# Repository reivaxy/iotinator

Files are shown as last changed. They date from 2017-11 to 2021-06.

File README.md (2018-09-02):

# iotinator

## The DIY multipurpose home iot solution.

### Some use cases

You come home, use your phone to browse to http://my.iotinator.com and turn on the light of the living room and adjust its brighness.

You are about to come home, use your phone to remotely turn the heater on so that the appartment is comfy when you get there.

You are on vacation, receive alerts if your aquarium temperature drops abnormally.

... etc, etc.

### Project description

TL;DR: This is not just a framework or a library, it's an iot application you can already use. Please check the Wiki for a detailed walk-through introduction and many pictures: https://github.com/reivaxy/iotinator/wiki

Here is the master module with a prototype switch module

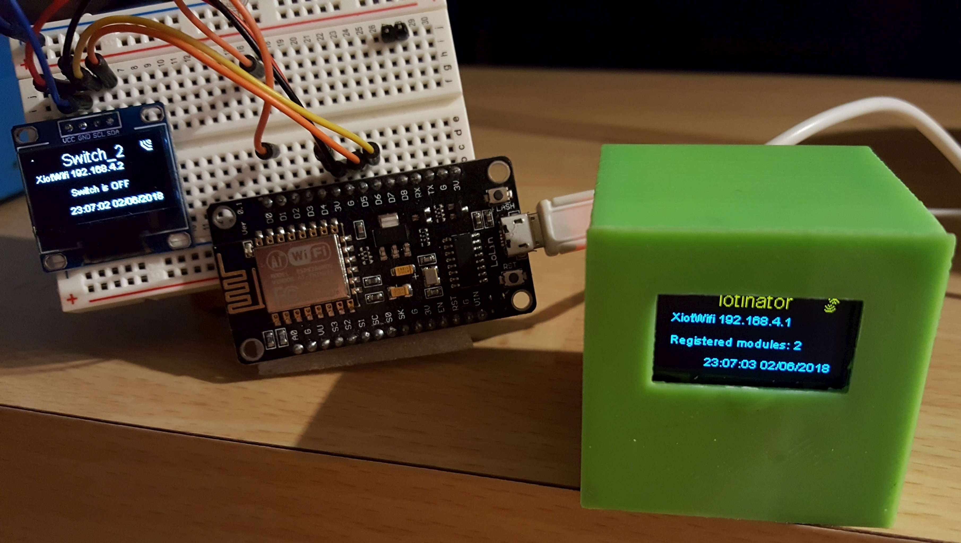
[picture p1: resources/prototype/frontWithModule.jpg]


And here is the switch module encased and functional:

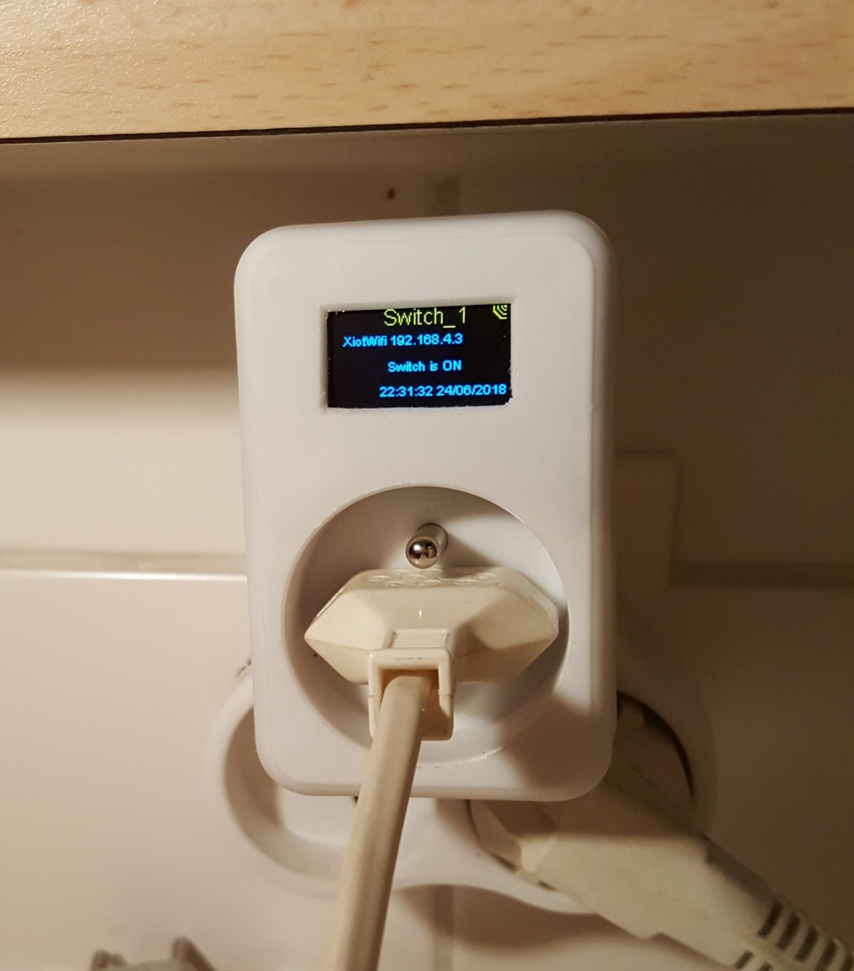
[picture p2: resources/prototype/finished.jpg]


You can easily build already available modules, which are usually just a few dollars of very easy to find hardware.

But you can easily design your own modules to fit your needs: in just a few lines of code, you can design a module able to connect to a wifi network, and equipped with a tiny Oled screen, to monitor something or control it, and make its collected data and actions available through a webApp showing all connected modules, but also through sending and receiving GSM text messages (not yet ready).

You can also update your modules wirelessly once in place, to keep improving them.

Some can operate using a small battery, others will need a power adapter, others can run directly on your main power source, or on a solar source.

Examples of modules are:
- Turning on/off a lamp, a heater, an air conditionner (Existing https://github.com/reivaxy/iotSwitch module)
 
 Here is a picture of this module's Oled display (Don't be fooled by its blurry aspect, the screen is actually sharp and good looking)
 
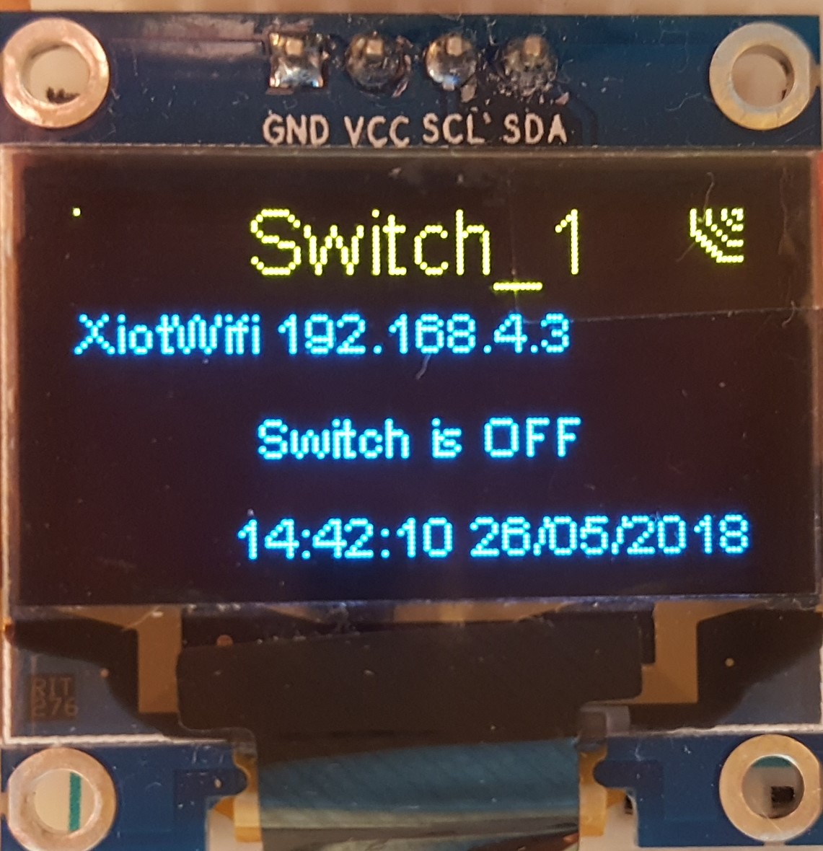
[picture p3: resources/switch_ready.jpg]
  
  
- A programmable scheduler to turn on/off random devices. Derived from the iotSwitch module by just adding some scheduling feaures.
- Monitoring for water leaks to send alerts (push, sms, ...)
- Monitoring for fire/fumes to send alerts
- Monitoring an aquarium parameters to alert when something's off (the very source of this project idea, which I had while working on https://github.com/reivaxy/aquaMonitor)
- Controlling various devices through their IR remote control port, replacing many remote controls with the advantage of working according to a programmed schedule, or remotely from home, which can be nice to set the heater or A/C on a little before coming home.
- You name it !

### And if you want to know more...

Let's dive deeper:

Xiot is a framework consisting of set of classes available as libraries, that make easy Wifi connection, Oled screen display, information exchange, web app interface.

An Xiot swarm is composed of a iotinator "master" module, and a bunch of agent modules (bunch start at one...).

Iotinator is the master module of the Xiot framework.

Its goal is to control many different devices by SMS or through a webApp (or mobile app), it's the common entry (and exit) point of communication. Once the master module is configured, adding a module is zero configuration: power the module up, reset the master, the new module will connect, and they'll negociate what happens next, which is use a private wifi network. Pre existing and connected modules will be disconnected for 30 seconds and automatically reconnect.

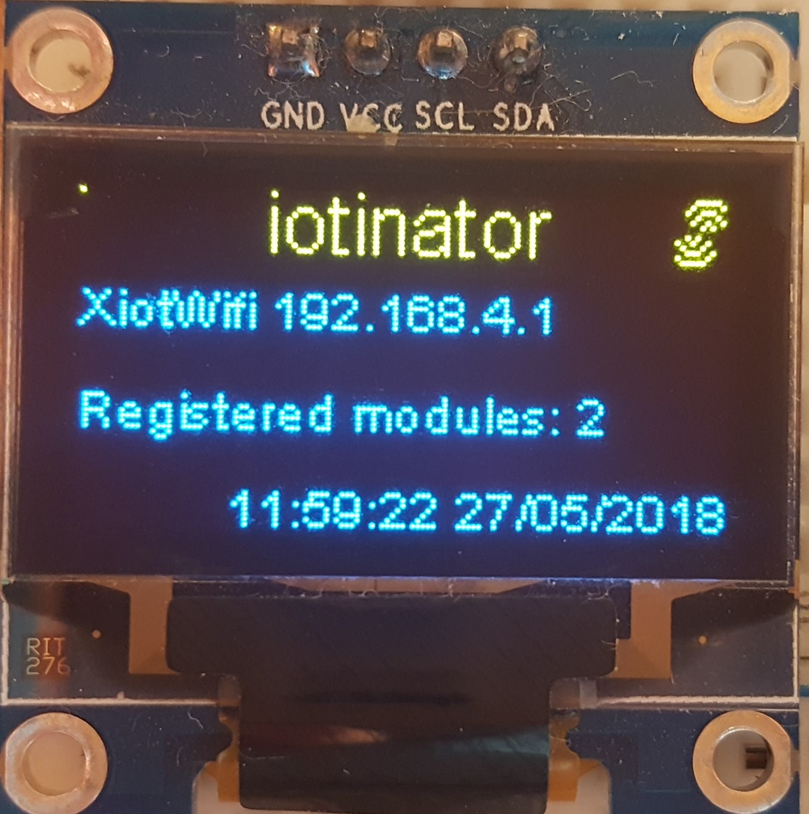
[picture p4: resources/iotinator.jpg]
  

Designing a new module can be just a few lines of code, depending on its complexity, of course.

The master and the modules run on esp8266 hardware (will investigate esp32 hardware too, one board having an Oled screen already integrated), connected to a SIM900 chip and an Oled screen, and offers an interface to agent modules in order to monitor them through SMS and webApps.

The Iotinator master module exposes APIs to communicate with the modules, and dispatches and forwards messages received by SMS or from the web app to them, and sends their responses back.

These API also allow modules to record logs, stats, etc on a website, and expose a web UI for module configuration and status diplay.

It connects to a domestic Wifi network to get time through NTP servers (but it can also get time from GSM network), and record logs and stats on a web server, much like http://reeftankalert.com/chart.php) and exposes a "private" Wifi network to communicate with agent modules.

Configuration is persisted in EEPROM, it uses network autodiscovery, (re)connection management is automatic.

# Current Status:

Waiting to solve stability issues with cheap GSM boards, gsm handling has been disabled.

GSM will be an option, the framework being able to work just using internet.

But GSM is nice in case of power outage (modules can have batteries, but my adsl box doesn't), and also to handle security
(sending codes to validate authentication for instance)

Current time is fetched from NTP servers once Home Wifi is configured and connected. The master module registers to the parameterized website (default is http://www.iotinator.com, whose files are in the webSite directory), so that if your phone is connected to the same network, typing http://my.iotinator.com will redirect you to the webApp.

The framework currently allows to create a new module in :
* a few lines of CPP in which you implement your custom eeprom persisted settings and behaviors, including displaying custom info on the Oled screen.
* a few lines of JS and CSS in which you implement the custom UI elements exposed on the webApp

The framework takes care of wifi connection to the iotinator master, registration, data exchange, polling, time and display management.

To create a new module, just get the iotSwitch repo, rename it, and the files within, and the classes they contain, and the code is totally self explanatory (No, just kidding).

For now the UI files (js, css) of each module are in the iotinator repository, which is not awesome...

The UI framework is taking care of displaying one block for each module connected with their connection information and providing the module's generic and custom data, and each module needs to provide the UI elements to display/handle its custom data within these blocks, and send actions to the REST api.

The UI part is not offering enough in terms of framework, and may change drastically. I'd like to investigate a vueJs or mobxJs version. Several UIs could easily be made available at the same time anyway.

Most UI files (all but one) need to be hosted on a public web server, because of low capacity on ESP8266 both in terms of storage and performances. I don't want to bloat it with an SD card, it has better things to do.

The js and css files are loaded from the minimalist loader page served by the module to build the webApp, which allows to modify the webApp without the need for flashing the ESP8266 to improve it, or translate messages. This also makes using images really easier, and contributes to faster page loading, since the wifi module does not have a great bandwidth (and does not process multiple requests simultaneously).

Of course you'll need to add the .htaccess directive:

Header set Access-Control-Allow-Origin "*"

In the wiki, you'll find all the information to setup your development environment, the libraries to install, and the necessary hardware.

https://github.com/reivaxy/iotinator/wiki

Picture of the early prototype with its SIM800 board:

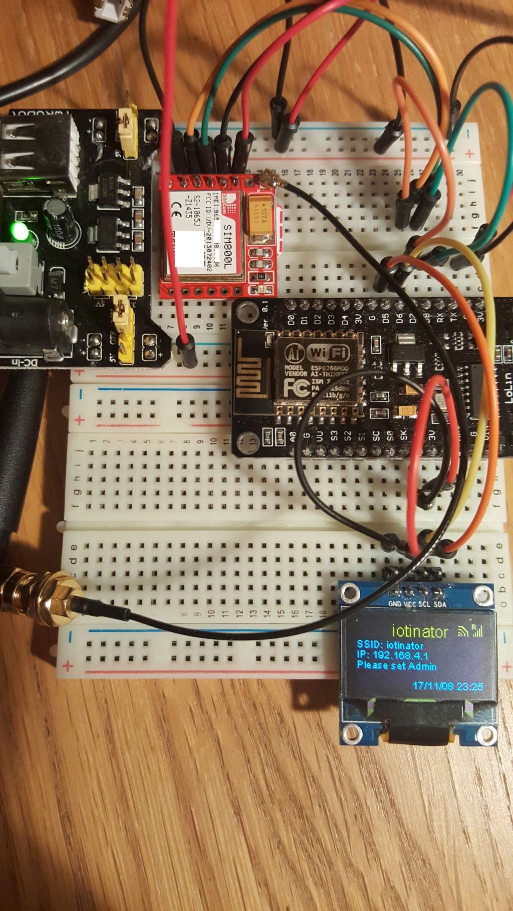
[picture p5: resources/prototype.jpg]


Screen shot of the POC of the webApp, showing 3 connected modules.

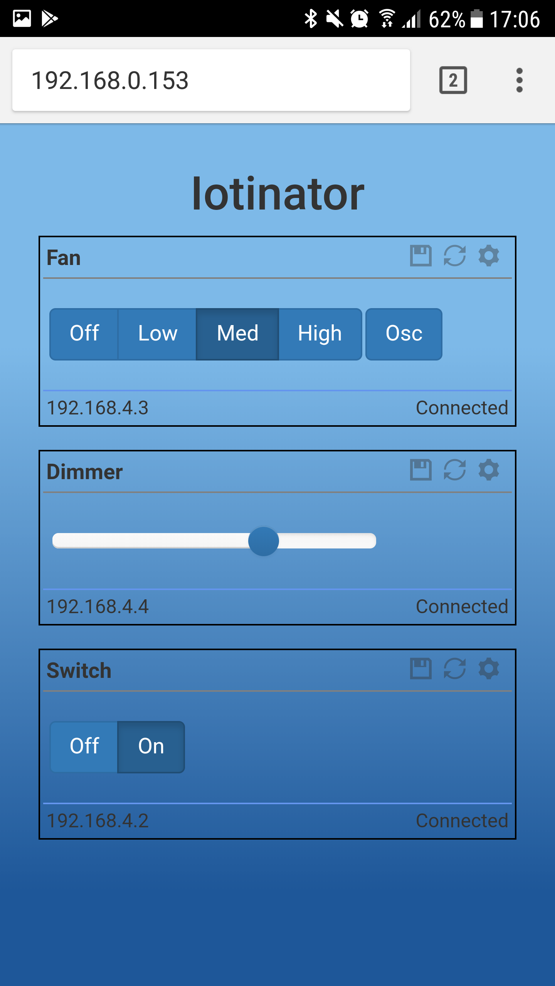
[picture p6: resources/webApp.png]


The data is refreshed every 10 seconds and reflects the status of the modules. A click on the button allows to control the Switch.

The UI is using Backbone and Bootstrap. A less than 1K page is served by the master ESP8266, and the rest of the API (libs, css, js) are hosted on a regular public server.

It's fast and light !

The iotSwitch module (https://github.com/reivaxy/iotSwitch) is basic but some will be more complex soon (Most of it coming from my previous project https://github.com/reivaxy/aquaMonitor/blob/master/res/webApp.png)

The iotFan (https://github.com/reivaxy/iotFan) module is merely a module that can control 4 switches, I used it in an old fan to remotely select its rotation speed.

The iotDimmer (https://github.com/reivaxy/iotDimmer) module is a dimmer I use to control the light level in my living room. It can also be used to control the speed of a fan (will depend on the motor technology, though).

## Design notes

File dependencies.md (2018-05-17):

https://github.com/esp8266/Arduino/tree/master/libraries/ESP8266WebServer

ESP8266WiFi

git@github.com:ThingPulse/esp8266-oled-ssd1306.git 

http://www.arduino.cc/en/Reference/Ethernet

NtpClientLib by German Martin 2.5.0
Time by Michael Margoli1.5.0

- https://github.com/reivaxy/XOLEDDisplay.git 
- https://github.com/reivaxy/XIOTDisplay.git
- https://github.com/reivaxy/XEEPROMConfig.git
- https://github.com/reivaxy/XUtils.git
- https://github.com/reivaxy/XIOTModule.git

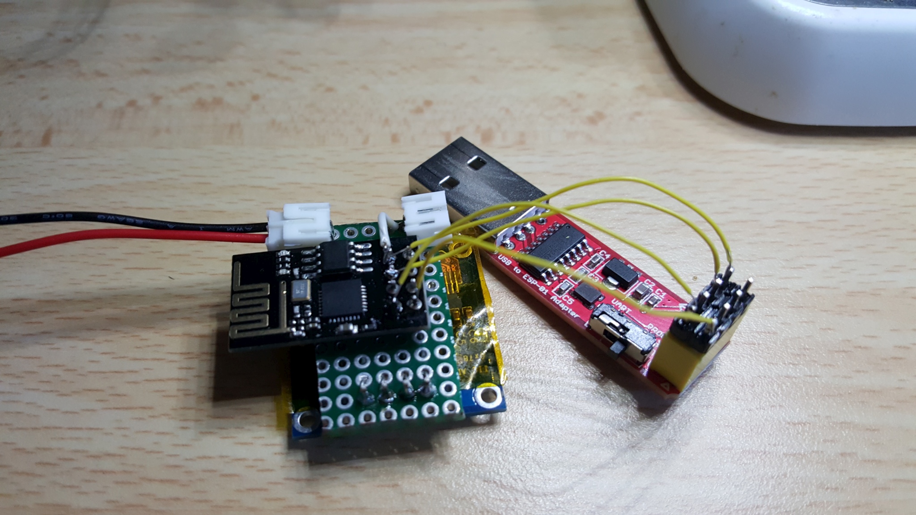
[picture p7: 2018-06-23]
resources/prototype/reFlash.jpg

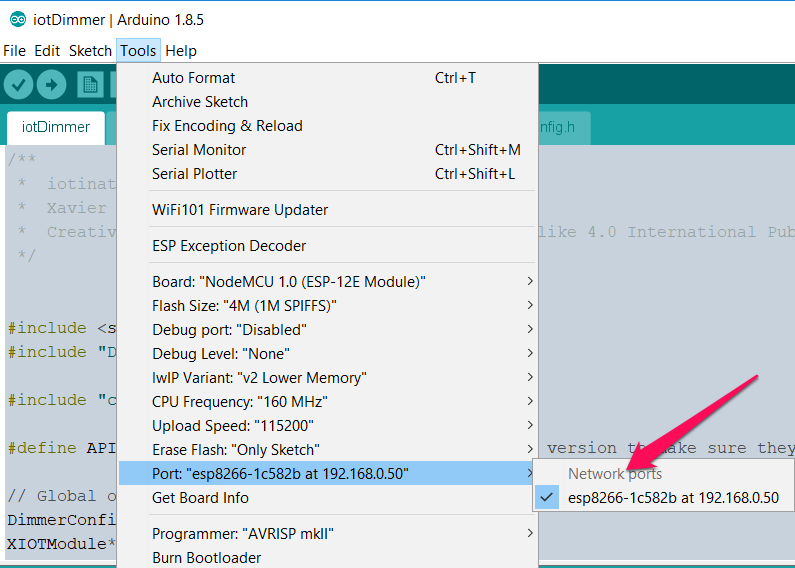
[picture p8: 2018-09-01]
resources/OTA/wifiPort.png

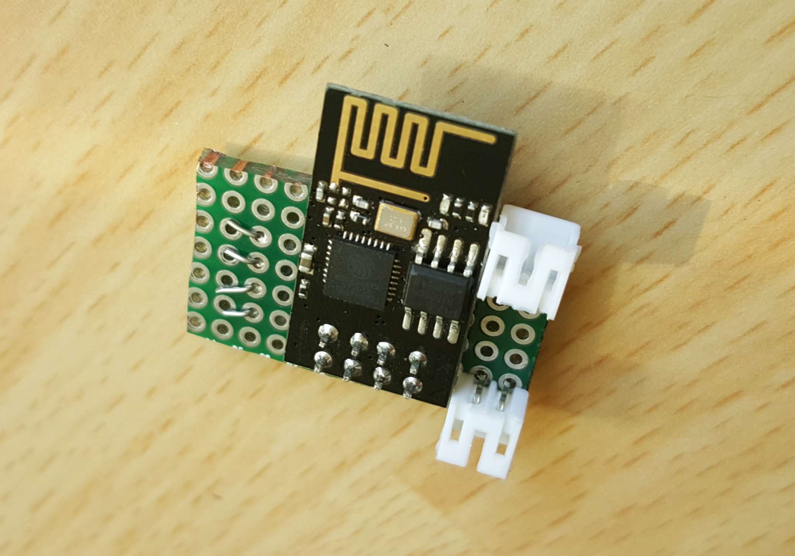
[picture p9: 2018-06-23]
resources/prototype/esp01.jpg

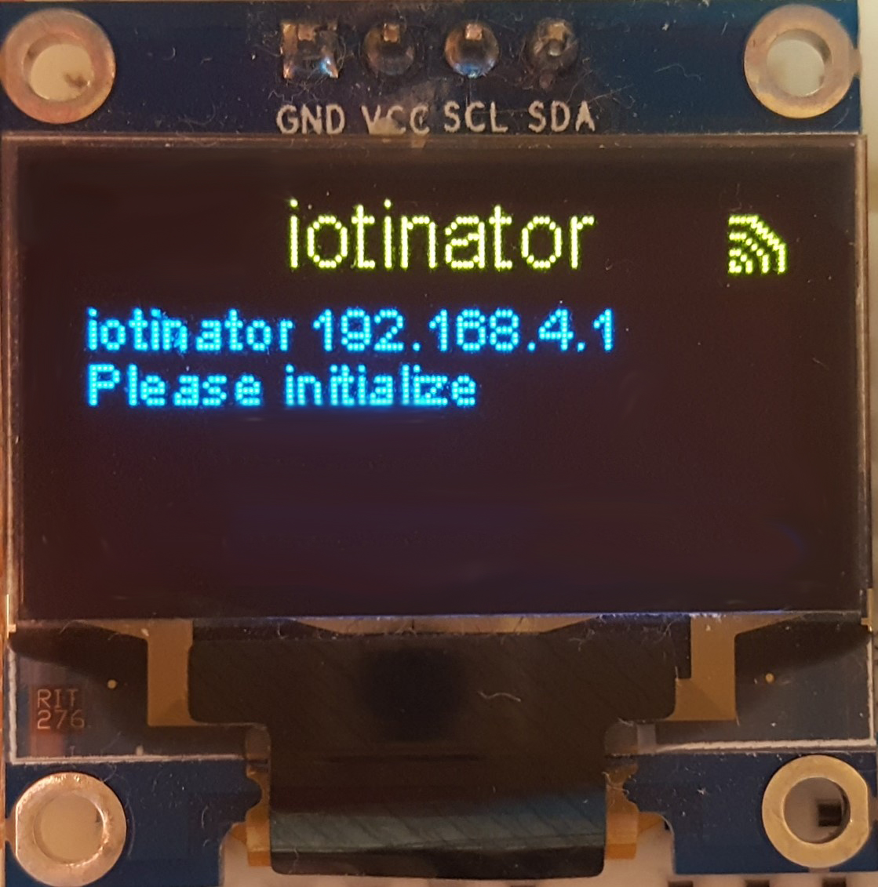
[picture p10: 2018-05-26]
resources/iotinator_init.jpg

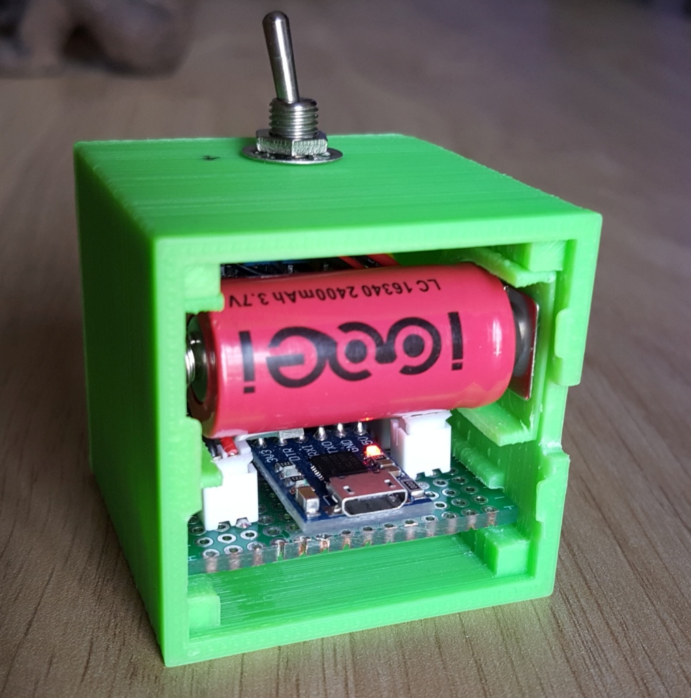
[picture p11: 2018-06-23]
resources/prototype/withBattery.jpg

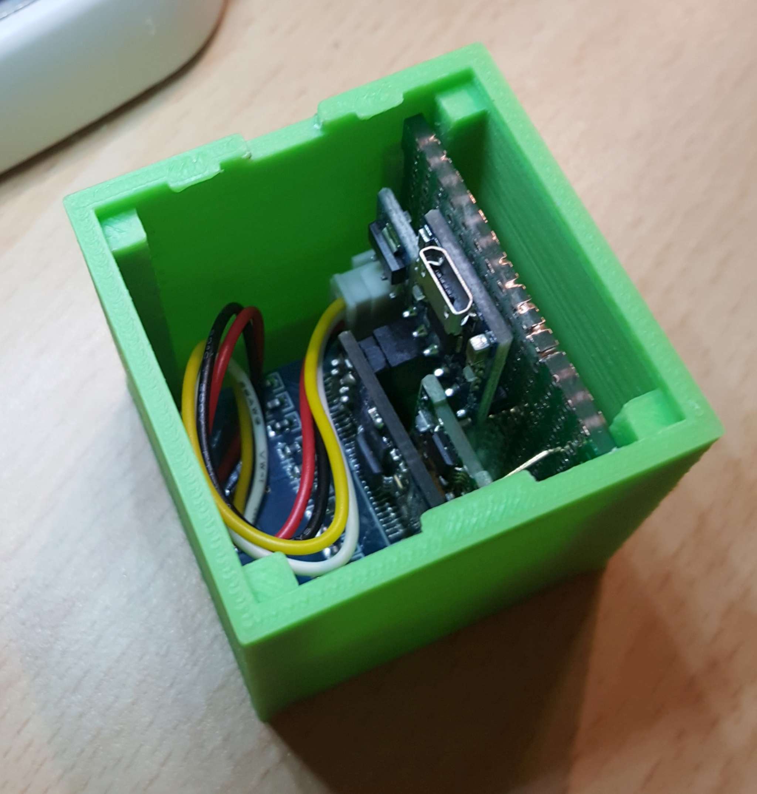
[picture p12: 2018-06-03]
resources/prototype/inside.jpg

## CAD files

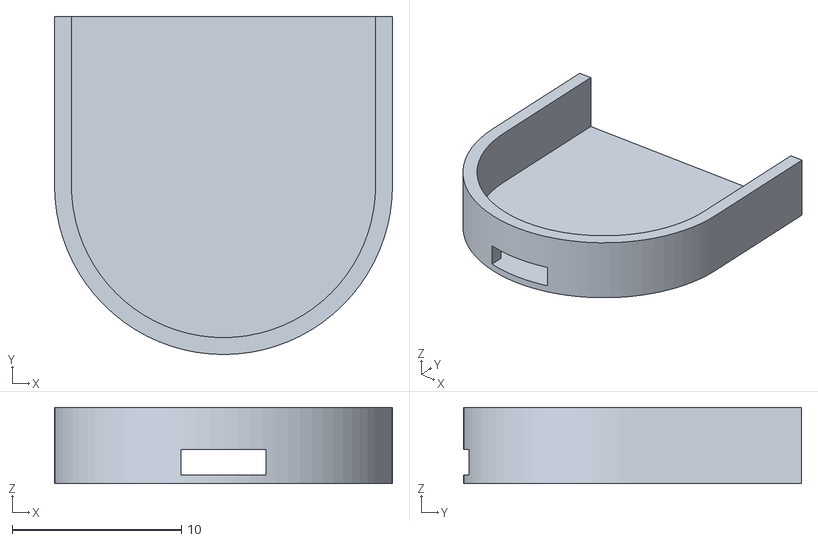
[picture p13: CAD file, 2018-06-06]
hardware/prototype/battery.stl
20.0 x 20.0 x 4.50

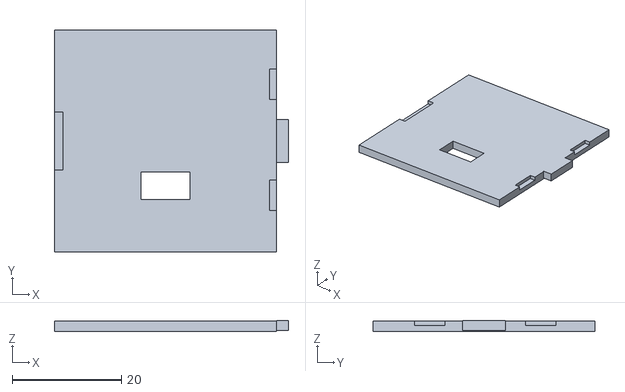
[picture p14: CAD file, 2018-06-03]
hardware/prototype/cover.stl
42.8 x 40.6 x 2.00

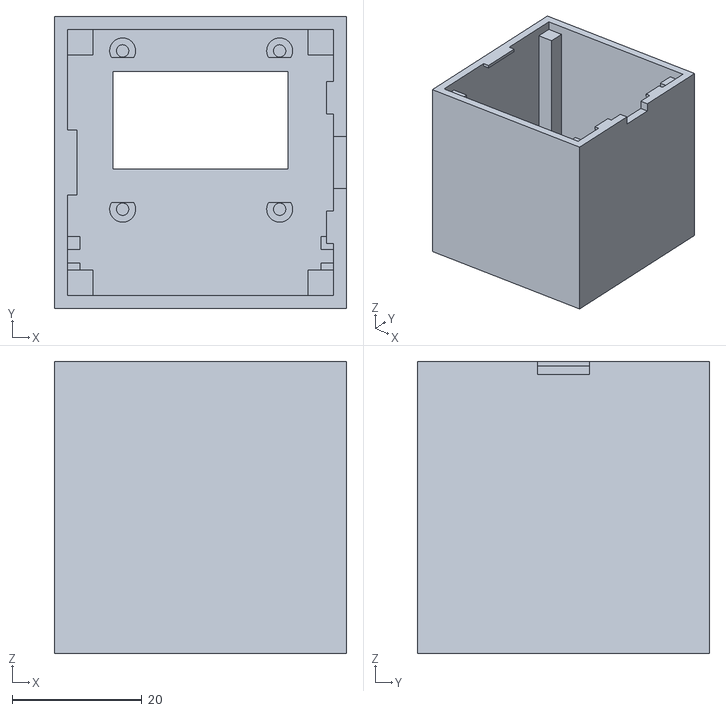
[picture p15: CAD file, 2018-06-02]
hardware/prototype/prototype.stl
45.0 x 45.0 x 45.0

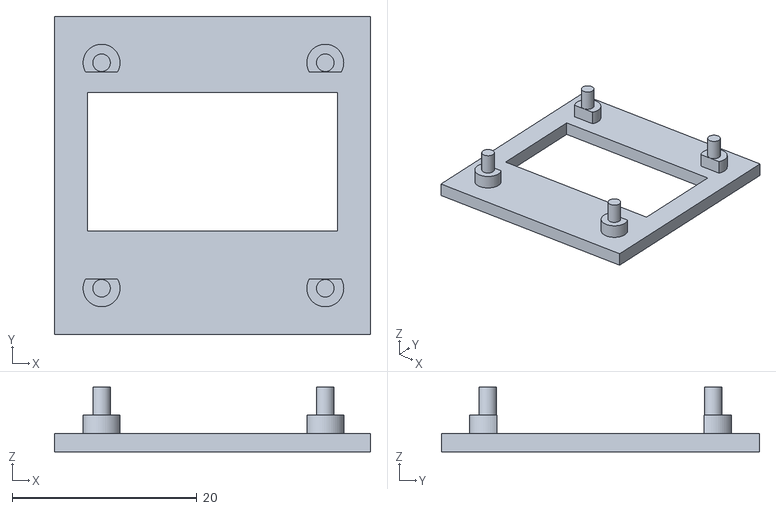
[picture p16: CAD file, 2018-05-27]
hardware/prototype/oledPanel.stl
34.2 x 34.4 x 7.00

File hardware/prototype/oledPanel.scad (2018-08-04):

// Oled screen panel

// Screen dimensions (may vary a little)
screenX = 28.5;
screenY = 27.5;

// Dimensions between holes axis
xInterHole = 23.7;
yInterHole = 24.4;

// Dimensions of the window in the panel
xWindow = 27;
yWindow = 15;
yWindowoffset = 1.5;

// Some offset
xHoleCenter = 0.1;
yHoleCenter = 0;

//rWindowPanel(45, 45, 2, 6);
//windowPanel(45, 45, 2, 6);

module rWindowPanel(x, y, z, yOffset) {
  translate([y/2, x/2, 0])
    rotate(90, [0, 0, 1])
      translate([-x/2, -y/2, 0])
        windowPanel(x, y, z, yOffset);
}

module windowPanel(x, y, z, yOffset) {
  xPanel = x;
  yPanel = y;
  zPanel = z;
  
  difference() {
    oledPanel(xPanel, yPanel, zPanel, yOffset);
    translate([(xPanel - xWindow)/2, (yPanel - yWindow)/2 + yWindowoffset + yOffset, -zPanel/2]) {
      // opening
      cube([xWindow, yWindow, 2 * zPanel]);  
    }
  }
}


module oledPanel(xPanel, yPanel, zPanel, yOffset) {   
  xMargin = xPanel - xInterHole;
  yMargin = yPanel - yInterHole;
  difference() {
    union() {
      cube([xPanel, yPanel, zPanel]);  
      pillar(xHoleCenter, yHoleCenter + yOffset, xMargin, yMargin, zPanel);
      pillar(xHoleCenter + xInterHole, yHoleCenter + yOffset, xMargin, yMargin, zPanel);
      pillar(xHoleCenter, yHoleCenter + yInterHole + yOffset, xMargin, yMargin, zPanel);
      pillar(xHoleCenter + xInterHole, yHoleCenter + yInterHole + yOffset, xMargin, yMargin, zPanel);
    }
    // cut the base of pillars
    translate([(xMargin - yInterHole)/2,  yMargin/2+1 + yOffset, zPanel]) {
      cube([xInterHole *2, yInterHole - 2, 3]);
    }
  }
}

// To hold the Oled screen
module pillar(x, y, xMargin, yMargin, zPanel) {
  echo (x, y, xMargin, yMargin, zPanel);
  translate([x + xMargin/2, y + yMargin/2, zPanel]) {
    cylinder(d=1.6, h=5, $fn=50);
    cylinder(d=4, h=1.5, $fn=50);
  }
    
}

// Screen model to make simulations
module screen() {
  screenY2 = 19;
  z1 = 1.2;
  z2 = 1.5;
  sBottomOffset = 3.7;

  xMargin = screenX - xInterHole;
  yMargin = screenY - yInterHole;
  
  translate([0, sBottomOffset, 0]) {
    cube([screenX, screenY2, z2]);
  }
  translate([0, 0, z2]) {
    difference() {
      cube([screenX, screenY, z1]);
      hole(xHoleCenter, yHoleCenter, xMargin, yMargin, z1);
      hole(xHoleCenter + xInterHole, yHoleCenter, xMargin, yMargin, z1);
      hole(xHoleCenter, yHoleCenter + yInterHole, xMargin, yMargin, z1);
      hole(xHoleCenter + xInterHole, yHoleCenter + yInterHole, xMargin, yMargin, z1);
      // pin placeholders
      translate([(screenX - 11)/2, screenY-3, z1 - 0.1]) {
        cube([11, 2.6, 1]);
      }
    }
  }
}

module hole(x, y, xMargin, yMargin, z) {
  translate([x + xMargin/2, y + yMargin/2, -0.1]) {
    cylinder(d=1.9, h = z+0.2, $fn=20);
  }
  
}

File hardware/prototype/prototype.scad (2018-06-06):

include <oledPanel.scad>;


innerX = 41;
innerY = 41;
innerZ = 41;
wall = 2;

outerX = innerX + 2 * wall;
outerY = innerY + 2 * wall;
outerZ = innerZ + 2 * wall;

boardZ = 2.25;

leftHookY = 10;
leftHookZ = 0.7;
leftHookX = 1.5;

rightHookY = 5;
rightHookZ = 0.7;
rightHookX = 1.1;

indentX = wall;
indentY = 8;
indentZ = wall;

rail = 2;
corner = 4;

batteryBracket();

//cover();
// iotinator();
//closed();

module closed() {
  iotinator();
  translate([wall + coverTolerance/2, wall + coverTolerance/2, outerZ - wall]) {
    cover();
  }
}


module batteryBracket() {
  x = 20;
  x2 = 18;
  z = 4.5;
  difference() {
    union() {
      cube([x, x/2, z]);
      translate([x/2, 0, 0]) {
        cylinder(d=x, h=z, $fn=80);
      }
    }
    union() {
      translate([x/2, 0, 0.5]) {
        cylinder(d = x2, h = z, $fn = 80);
      }
      translate([(x - x2)/2, 0, 0.5]) {
        cube([x2, x2, z]);
      }
    }
    translate([(x - 5)/2, -x/2, 0.5]) {
      cube([5, 1.5, 1.5]);
    }
  }
}


module iotinator() {
  windowPanel(outerX, outerY,  wall, 4);  
  difference() {
    // outer cube
    cube([outerX, outerY, outerZ]);
    translate([wall, wall, -wall]) {
      // inner cube
      cube([innerX, innerY, innerZ + 4 * wall]);
    }
    
    // Small opening for the cover
    translate([innerX + wall -1 , (outerY - indentY)/2, outerZ-indentZ]) {
      cube([indentX + 2, indentY, indentZ+1]);
    }      
  }
  
  // bottom left rail
  translate([wall, wall + corner, 0])
    cube([rail, rail, innerZ-5]);
  // top left rail
  translate([wall, wall + corner + rail + boardZ, 0])
    cube([rail, rail, innerZ-5]);
  // bottom right rail
  translate([innerX + wall - rail , wall + corner, 0])
    cube([rail, rail, innerZ-5]);
  // top right rail
  translate([innerX + wall - rail , wall + corner + rail + boardZ, 0])
    cube([rail, rail, innerZ-5]);
  
  // bottom left corner
  translate([wall, wall, wall])
    cube([corner, corner, innerZ]);
  // top left corner
  translate([wall , innerY + wall - corner , wall])
    cube([corner, corner, innerZ]);
    
  // bottom right corner
  
  translate([innerX + wall - corner, wall, wall])
    cube([corner, corner, innerZ]);
  // top right corner
  translate([innerX + wall - corner, innerY + wall - corner, wall])
    cube([corner, corner, innerZ]);
  
  // left cover Hook
  translate([wall, (outerY - leftHookY)/2, outerZ-leftHookZ]) {
    cube([leftHookX, leftHookY, leftHookZ]);
  }
  
  color("red") {
    // bottom right cover Hook
    translate([outerX - rightHookX - wall, (outerY - rightHookY)/4, outerZ-rightHookZ ]) {
      cube([rightHookX, rightHookY, rightHookZ]);
    }
    // top right cover Hook
    translate([outerX - rightHookX - wall, (outerY - rightHookY) - (outerY - rightHookY)/4, outerZ-rightHookZ ]) {
      cube([rightHookX, rightHookY, rightHookZ]);
    }   
  }
}

coverTolerance = 0.4;
coverX = innerX - coverTolerance;
coverY = innerY - coverTolerance;
usbSocketX = 9;
usbSocketY = 5;
usbSocketYOffset = 9.6;

module cover() {
    union() {
      difference() {
        cube([coverX, coverY, wall - 0.1]);
        
        translate([0, (coverY - leftHookY - 0.6)/2, wall - leftHookZ - 0.2])
          cube([leftHookX +0.1, leftHookY + 0.6, rightHookZ + 2 ]);
        
        // bottom right cover Hook
        translate([coverX - rightHookX -0.2, (coverY - rightHookY - 0.6)/4 - (wall + coverTolerance)/2,  wall - rightHookZ - 0.2]) {
          cube([rightHookX+0.2, rightHookY+0.6, rightHookZ + 2]);
        }
        // top right cover Hook
        translate([coverX - rightHookX -0.2,  
                   (coverY - rightHookY -0.2) - (coverY - rightHookY - 0.6)/4  + (wall + coverTolerance)/2,
                    wall - rightHookZ - 0.2 ]) {
          cube([rightHookX+0.2, rightHookY+0.6, rightHookZ + 2]);
        }
        // usb socket
        translate([(coverX - usbSocketX)/2, usbSocketYOffset, -0.5]) {
          cube([usbSocketX, usbSocketY, wall + 1]);  
        }

      }
      translate([coverX , (coverY - indentY + 0.2)/2, 0.2]) {
        cube([indentX + 0.2, indentY - 0.2, wall - 0.2]);
      }
    }
  
  
}

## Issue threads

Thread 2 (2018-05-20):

Name suffixed with "_1" upon registration

reivaxy, 2018-05-20:
even when no collision

reivaxy, 2023-10-25:
This is a test
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

reivaxy, 2023-10-25:
You'll need 4 M3**10 hex screws and nuts. M3**12 and M3**14 also work.

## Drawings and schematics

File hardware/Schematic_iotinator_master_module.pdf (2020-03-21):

+-

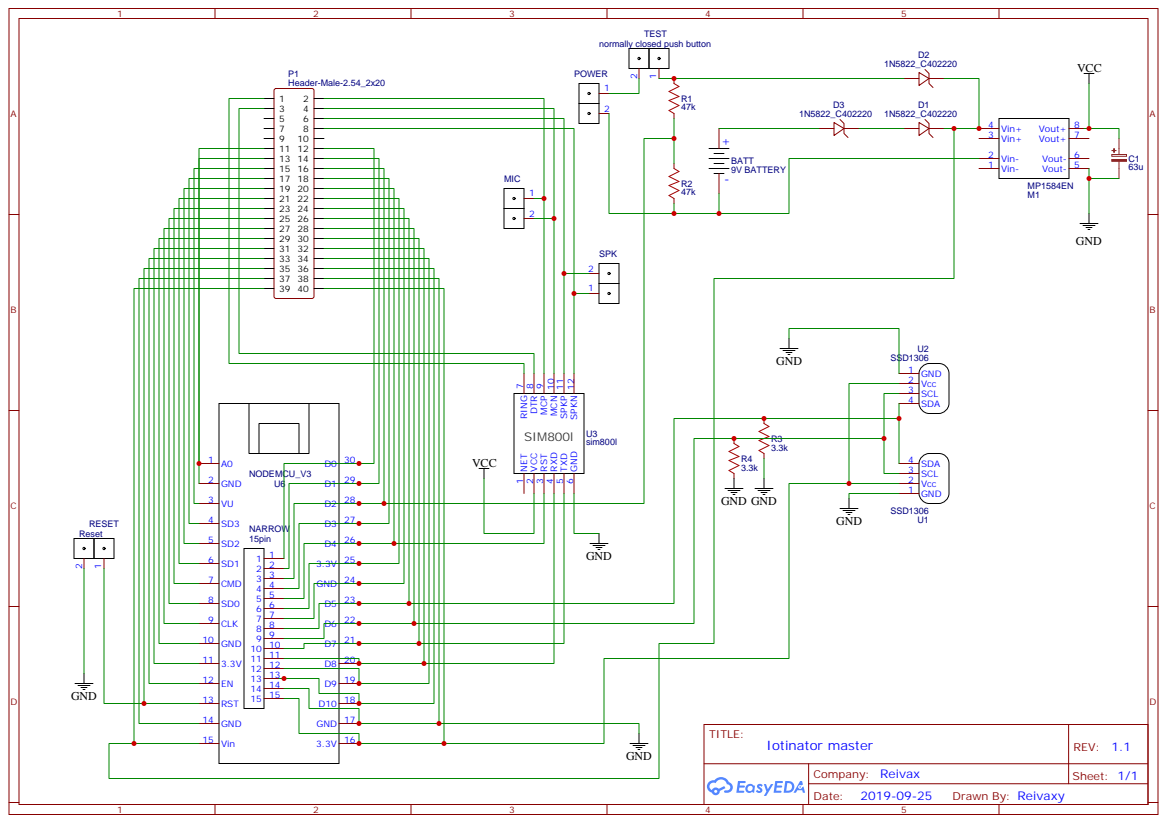
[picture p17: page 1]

normally closed push button

sim800l SIM800l U3 NET 1 VCC 2 RST 3 RXD 4 TXD 5 GND 6 RING ⁷ DTR 8 MCP 9 MCN ¹⁰ SPKP 11 SPKN ¹²

D6 22
D7 21

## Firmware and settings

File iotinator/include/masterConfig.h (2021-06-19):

/**
 *  Definition of the config data structure for the master module and the class to persist it to EEPROM 
 *  Xavier Grosjean 2017
 *  Creative Commons Attribution-NonCommercial-ShareAlike 4.0 International Public License
 */
 
#pragma once
#include <Arduino.h>
#include "registeredPhoneNumber.h"
#include <XIOTConfig.h>
#include <XUtils.h>

#define CONFIG_VERSION 4
#define MODULE_NAME "iotinator"

#define HOSTNAME_MAX_LENGTH 50
#define API_KEY_MAX_LENGTH 40
#define DEFAULT_WEBSITE "http://www.iotinator.com/"
#define DEFAULT_NTP_SERVER "0.europe.pool.ntp.org"

#define DEFAULT_STAT_PERIOD 1800000 // Half an hour. Should 0 be default ?

#define DEFAULT_GMT_HOUR_OFFSSET 2
#define DEFAULT_GMT_MIN_OFFSSET 0

struct MasterConfigStruct:XEEPROMConfigDataStruct {
  // First 2 members (version and type) are inherited from XEEPROMConfigDataStruct   
  char name[NAME_MAX_LENGTH + 1]; 
  // Array to store phone number information, permissions, ...
  phoneNumberDataType registeredNumbers[MAX_PHONE_NUMBERS];
  // Hostname for webapps, statistics, etc
  char webSite[HOSTNAME_MAX_LENGTH + 1];
  
  // API KEY from website registration, it's a uuid, 36 char
  char apiKey[API_KEY_MAX_LENGTH + 1];
    
  // ntp server
  char ntpHostName[HOSTNAME_MAX_LENGTH + 1];


  // Period at which statistics are sent to web server. 0 means no stat sent
  unsigned int statPeriod = DEFAULT_STAT_PERIOD;
  
  char homeSsid[SSID_MAX_LENGTH + 1];
  char homePwd[PWD_MAX_LENGTH + 1];
    
  char apSsid[SSID_MAX_LENGTH + 1];
  char apPwd[PWD_MAX_LENGTH + 1];
  int defaultAPExposition = DEFAULT_AP_EXPOSITION;
  
  int8_t gmtHourOffset = DEFAULT_GMT_HOUR_OFFSSET;
  int8_t gmtMinOffset = DEFAULT_GMT_MIN_OFFSSET;
  
  char simPin[5]; // sim code for sim card
  
};

 
class MasterConfigClass:public XEEPROMConfigClass {
public:
  MasterConfigClass(unsigned int version, const char* name);
  virtual void initFromDefault(void) override;
  
  RegisteredPhoneNumberClass* getRegisteredPhoneByNumber(const char* number); 
  RegisteredPhoneNumberClass* getRegisteredPhone(unsigned int offset); 
  void removePhone(const char*);
  void addPhone(const char*);
  char* getName(void);
  void setName(const char*);   
  void setHomeSsid(const char* ssid);
  void setWebSite(const char* webSite);
  void setWebSite(String webSite);
  void setApiKey(const char* apiKey);
  void setApiKey(String apiKey);
  void setNtpServer(String ntpServer);
  void setNtpServer(const char *ntpServer);
  void setHomeSsid(String ssid);
  void setHomePwd(const char* pwd);
  void setHomePwd(String pwd);
  void setApSsid(const char* ssid);
  void setApSsid(String ssid);
  void setApPwd(const char* pwd);
  void setSimPin(const char* pwd);
  void setApPwd(String pwd);
  char* getHomeSsid(void);
  char* getWebSite(void);
  char* getApiKey(void);
  char* getNtpServer(void);
  char* getHomePwd(void);
  char* getApSsid(bool force=false);
  char* getApPwd(bool force=false);
  char* getSimPin();
  void setDefaultAPExposition(int delay);
  unsigned int getDefaultAPExposition(void);
  
  bool isHomeWifiConfigured(void);
  bool isAPInitialized(void);
  void setAdminNumber(char *number);
  void setAdminNumber(String numberString);
  char* getAdminNumber();
  void setGmtOffset(int8_t hour, int8_t min); 
  int8_t getGmtHourOffset(); 
  int8_t getGmtMinOffset(); 
  
protected:
  RegisteredPhoneNumberClass* _phoneNumbers[MAX_PHONE_NUMBERS];
  MasterConfigStruct* _getDataPtr(void);  
};

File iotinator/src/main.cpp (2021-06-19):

/**
 *  iotinator master module 
 *  Xavier Grosjean 2017
 *  Creative Commons Attribution-NonCommercial-ShareAlike 4.0 International Public License
 */

#include <ESP8266mDNS.h>
#include <ArduinoJson.h>
#include <stdio.h>
#include <TimeLib.h>
#include <NtpClientLib.h>
#include <XIOTDisplay.h>
#include <XIOTModule.h> 

#include "masterConfig.h"
#include "AgentCollection.h"

#include "initPageHtml.h"
#include "appLoader.h"
#include "appGLALoader.h"

#define TIME_STR_LENGTH 100
#define MAX_MSG_LENGTH 1000
#define API_VERSION "1.0"    // modules can check API version to make sure they are compatible...

// Global object to store config
MasterConfigClass *config;

DisplayClass *oledDisplay;
DisplayClass *oledDisplay2;

#include "iotinatorSecrets.h"
#include "gsm.h"
// SIM800 TX is connected to RX MCU 13 (D7)
#define SIM800_TX_PIN 13
// SIM800 RX is connected to TX MCU 15 (D8)
#define SIM800_RX_PIN 15
// SIM800 Reset is connected to TX MCU 2 (D4)
#define SIM800_RESET_PIN 2

#define POWER_ALERT_INTERVAL 20*60*1000

SoftwareSerial serialSIM800(SIM800_TX_PIN, SIM800_RX_PIN, false);
GsmClass gsm(&serialSIM800, 2);
#include "gsmMessageHandlers.h"

ESP8266WebServer* server;
bool homeWifiConnected = false;
bool homeWifiFirstConnected = false;
NTPSyncEvent_t ntpEvent;
bool ntpEventToProcess = false;
bool ntpServerInitialized = false;
bool ntpTimeInitialized = false;
unsigned long elapsed200ms = 0;
unsigned long elapsed500ms = 0;
unsigned long elapsed2s = 0;
bool gsmEnabled = false;
MDNSResponder mdns;
time_t timeNow = 0; 
time_t timeLastTimeDisplay = 0;
time_t timeLastWifiDisplay = 0;
time_t timeLastPing = 0;
unsigned long lastPowerAlertSent = 0;
AgentCollection *agentCollection;
Agent* agentToRename = NULL;

char glaCss1[50];
char glaCss2[50];
char glaJs1[50];
char glaJs2[50];

int scl = 12;
int sda = 14;

int powerMonitorPin = 4;

// Warning: XIOTModule class does not yet handle STA_AP module, but provides nice utilities
// that we want to reuse here :) 
// TODO: when XIOTModule class can handle AP_STA, use it here to get rid of
// TODO: a lot of common code.
XIOTModule* module; 

// Handlers will work as long as these variables exists. 
static WiFiEventHandler wifiSTAGotIpHandler, wifiSTADisconnectedHandler,
                        stationConnectedHandler, stationDisconnectedHandler ;
bool defaultAP = true;
bool displayAP = false;
bool ntpListenerInitialized = false;
String ipOnHomeSsid;


void timeDisplay() {
  oledDisplay->clockIcon(!ntpTimeInitialized);
  
  // TODO: if no Home wifi, no NTP, => test if  GSM enabled and use its time
  
  time_t millisec = millis();
  if(ntpTimeInitialized && millisec > config->getDefaultAPExposition()) {
    oledDisplay->refreshDateTime(NTP.getTimeDateString().c_str());
  } else {
    char message[10];
    sprintf(message, "%dl", millisec/1000);
    oledDisplay->refreshDateTime(message);
    
  }
}

void wifiDisplay() {
  char message[100];
  WifiType wifiType = AP;
  
  if(config->isAPInitialized()) {
    oledDisplay->setLine(1, "", NOT_TRANSIENT, NOT_BLINKING);
  } else {
    oledDisplay->setLine(1, MSG_INIT_REQUEST, NOT_TRANSIENT, BLINKING);
  }
    
  if(displayAP && homeWifiConnected) {
    strcpy(message, config->getHomeSsid());     
    strcat(message, " ");
    ipOnHomeSsid.getBytes((unsigned char *)message + strlen(message), 50);
    oledDisplay->setLine(0, message);
  } else {
    strcpy(message, config->getApSsid());
    strcat(message, " ");
    IPAddress ipAddress = WiFi.softAPIP();
    ipAddress.toString().getBytes((unsigned char *)message + strlen(message), 50);
    oledDisplay->setLine(0, message);
  }
  displayAP = !displayAP;
  
  bool blinkWifi = false;
  if (!homeWifiConnected && config->isHomeWifiConfigured()) {
    blinkWifi = true;
  }
  
  if(config->isHomeWifiConfigured()) {
    wifiType = AP_STA;
  } 
  oledDisplay->wifiIcon(blinkWifi, wifiType);
}

// For now, use specific methods to load each app.
// Later: website could provide a manifest exposing all available apps, and their dependencies,
// and make this generic.
void printAppPage() {
  char *page = (char *)malloc(strlen(appLoader) + strlen(config->getWebSite()) + 1);
  sprintf(page, appLoader, config->getWebSite());
  module->sendHtml(page, 200);
  free(page);
}

void printAppGLAPage() {
  char *page = (char *)malloc(strlen(appGLALoader) 
  + strlen(config->getWebSite()) 
  + strlen(glaCss1) 
  + strlen(glaCss2) 
  + strlen(glaJs1) 
  + strlen(glaJs2) 
  + 1);
  sprintf(page, appGLALoader, config->getWebSite(), glaCss1, glaCss2, glaJs1, glaJs2);
  module->sendHtml(page, 200);
  free(page);
}

void printNumbers() {
  if(!gsmEnabled) return;
  for(int i = 0; i < MAX_PHONE_NUMBERS; i++) {
    Serial.print("Numero ");
    Serial.print(i);
    Serial.print(" ");
    Serial.print(config->getRegisteredPhone(i)->getNumber());
    Serial.println(config->getRegisteredPhone(i)->isAdmin()?" Admin":"");
  }
}

void printHomePage() {
  // If init already done, display page saying so, otherwise display init page
  
  // TODO Disabled for now, need to be enabled !!
  if (false && config->isAPInitialized()) {
    Serial.println("Init done Page");
    module->sendText(MSG_INIT_ALREADY_DONE, 200);
  } else {
  
    char *page = (char *)malloc(strlen(initPage) + 10);
    sprintf(page, initPage, gsmEnabled ? "": "noGsm");
    module->sendHtml(page, 200);
    free(page);
    server->on("/initSave",  HTTP_POST, [](){
      Serial.println("Rq on /initSave");
      
      // TODO: /initSave might need to be disabled once done ?
      if(false && config->isAPInitialized()) {
        module->sendHtml(MSG_ERR_ALREADY_INITIALIZED, 403);
        return;
      }
      
      // TODO add some controls
      if (false && !server->hasArg("apSsid")) {
        module->sendText(MSG_ERR_BAD_REQUEST, 403);
        return;
      }
      String adminNumber = server->arg("admin");
      if (adminNumber.length() > 0) {
        if (adminNumber.length() < 10) {
          module->sendText(MSG_ERR_ADMIN_LENGTH, 403);
          return;
        }
        config->setAdminNumber(adminNumber);
        gsm.sendSMS(config->getAdminNumber(), "You are admin");  //
        oledDisplay->setLine(2, ""); 
        oledDisplay->setLine(2, MSG_INIT_DONE, true, false); 
      }
      
      // TODO: add checks in the config methods
      // Read and save new AP SSID 
      String apSsid = server->arg("apSsid");
      if (apSsid.length() > 0) {
        // TODO: add checks
        config->setApSsid(apSsid);
        wifiDisplay();
      }
      // Read and save the web app server      
      String webSite = server->arg("webSite");
      if (webSite.length() > 0) {
        // TODO: add checks
        config->setWebSite(webSite);
      }
      // Read and save the api key      
      String apiKey = server->arg("apiKey");
      if (apiKey.length() > 0) {
        // TODO: add checks
        config->setApiKey(apiKey);
      }
            
      // Read and save the ntp host      
      String ntpHost = server->arg("ntpHost");
      if (ntpHost.length() > 0) {
        // TODO: add checks
        config->setNtpServer(ntpHost);
      }
      // Read and save new AP PWD 
      String apPwd = server->arg("apPwd");
      if( apPwd.length() > 0) {
        // Password need to be at least 8 characters
        if(apPwd.length() < 8) {
          module->sendText(MSG_ERR_PASSWORD_LENGTH, 403);
          return;
        }
        config->setApPwd(apPwd);
      }
            
      // Read and save home SSID 
      String homeSsid = server->arg("homeSsid");
      if (homeSsid.length() > 0) {
        config->setHomeSsid(homeSsid);
      }
      // Read and save home PWD 
      String homePwd = server->arg("homePwd");
      if( homePwd.length() > 0) {
        // Password need to be at least 8 characters
        if(homePwd.length() < 8) {
          module->sendText(MSG_ERR_PASSWORD_LENGTH, 403);
          return;
        }
        config->setHomePwd(homePwd);
      }
      
      // Read and save sim PIN
      String simPin = server->arg("simPin");
      if( simPin.length() > 0) {
        // simPin need to be 4 characters
        if(simPin.length() != 4) {
          module->sendText(MSG_ERR_PIN_LENGTH, 403);
          return;
        }
        config->setSimPin(simPin.c_str());
      }
            
      
      // TODO: when GSM connected, send code, display confirmation page, 
      // and save once code confirmed
      // in the meantime, just save
      config->saveToEeprom();
      
      // New Access Point
      WiFi.mode(WIFI_AP_STA);
      WiFi.softAP(config->getApSsid(), config->getApPwd());
      if(config->isHomeWifiConfigured()) {
        WiFi.begin(config->getHomeSsid(), config->getHomePwd());
      }
      
      printNumbers();
      module->sendText(MSG_INIT_DONE, 200);
      
    });     
  }
}

// Opens the Wifi network Access Point.
// For the first X seconds, it is the default one, then the custom one if configured.
void initSoftAP() {
  Serial.print(MSG_WIFI_OPENING_AP);
  Serial.println(config->getApSsid());
  // IPAddress ip(192, 168, 4, 1);
  // IPAddress gateway(192, 168, 4, 1);
  // IPAddress subnet(255, 255, 255, 0);
  // WiFi.softAPConfig(ip, gateway, subnet);
  WiFi.softAP(config->getApSsid(), config->getApPwd(), 1, false, 8);
  Serial.println(WiFi.softAPIP());
  wifiDisplay();
}

void onStationConnected(const WiFiEventSoftAPModeStationConnected& evt) {
  char message[50];
  sprintf(message, "Mac %02x:%02x:%02x:%02x:%02x:%02x\n", evt.mac[0], evt.mac[1], evt.mac[2], evt.mac[3], evt.mac[4], evt.mac[5]);
  oledDisplay->setLine(1, MSG_WIFI_STATION_CONNECTED, TRANSIENT, NOT_BLINKING);
  oledDisplay->setLine(2, message, TRANSIENT, NOT_BLINKING);  
}

void onStationDisconnected(const WiFiEventSoftAPModeStationDisconnected& evt) {
  oledDisplay->setLine(1, MSG_WIFI_STATION_DISCONNECTED, TRANSIENT, NOT_BLINKING);
  // TODO: remove it from agent collection ?
  // Disconnection needs a long time to be triggered (15mn ?)
  // May be periodic ping should be enough ?
}

// Called when STA is connected to home wifi and IP was obtained
void onSTAGotIP (WiFiEventStationModeGotIP ipInfo) {
  ipOnHomeSsid = ipInfo.ip.toString();
  Serial.printf("Got IP on %s: %s\n", config->getHomeSsid(), ipOnHomeSsid.c_str());
  homeWifiConnected = true;
  if(module->isWaitingOTA()) {
    char message[40];
    sprintf(message, "Ota: %s", ipOnHomeSsid.c_str());
    oledDisplay->setLine(0, message, NOT_TRANSIENT, NOT_BLINKING); 
    ArduinoOTA.begin();    
    return;
  }
  homeWifiFirstConnected = true;
  if (mdns.begin("esp8266", WiFi.localIP())) {
    Serial.println("MDNS responder started");
  }
  wifiDisplay();
}

void initNtp() {
  if(ntpServerInitialized) return;
  ntpServerInitialized = true;
  Serial.printf("Fetching time from %s\n", config->getNtpServer());
  NTP.begin(config->getNtpServer());
  NTP.setInterval(63, 7200);  // 63s retry, 2h refresh
  NTP.setTimeZone(config->getGmtHourOffset(), config->getGmtMinOffset());
}

void processNtpEvent() {
  if (ntpEvent) {
    Serial.print("NTP Time Sync error: ");
    if (ntpEvent == noResponse)
      Serial.println("NTP server not reachable");
    else if (ntpEvent == invalidAddress)
      Serial.println("Invalid NTP server address");
  } else {
    Serial.print("Got NTP time: ");
    Serial.println(NTP.getTimeDateString(NTP.getLastNTPSync()));
    ntpTimeInitialized = true;
    timeDisplay();
    NTP.setInterval(7200, 7200);  // 5h retry, 2h refresh. once we have time, refresh failure is not critical
  }
}
void onSTADisconnected(WiFiEventStationModeDisconnected event) {
  // Continuously get messages, so just output once.
  if(homeWifiConnected) {
    Serial.printf("Lost connection to %s, error: %d\n", event.ssid.c_str(), event.reason);
    homeWifiConnected = false;
    wifiDisplay();
    NTP.stop();
  }
}

void refreshOled2() {
  char* list = agentCollection->list();
  char *token = strtok(list, "\n");
  int line = 0;
  while(token) {
    oledDisplay2->setLine(line, token, NOT_TRANSIENT, NOT_BLINKING);
    token = strtok(NULL, "\n");
    line++;
  }
  free(list);
  oledDisplay2->refresh(); 
}

void addEndpoints() {
  server = module->getServer();  
  server->on("/", HTTP_GET, [](){
    if (config->isAPInitialized()) {
      if(server->arg("app") == "gla") {
        printAppGLAPage();
      } else {
        printAppPage();
      }
    } else {
      printHomePage();
    }
  });

  server->on("/init", HTTP_GET, [](){
    printHomePage();
  });

  server->on("/api/list", HTTP_GET, [](){
    int size = agentCollection->getCount();
    int customStrSize = 0;
    
    // Size estimation: https://arduinojson.org/assistant/
    // TODO: update this when necessary : 10 fields per agent (for now it's actually 8)
    const size_t bufferSize = size*JSON_OBJECT_SIZE(10)
                              + JSON_OBJECT_SIZE(size)
                              +  + JSON_OBJECT_SIZE(1) ;
    
    DynamicJsonBuffer jsonBuffer(bufferSize);
    JsonObject& root = jsonBuffer.createObject();    
    JsonObject& agentList = root.createNestedObject("agentList");
    
    agentCollection->list(agentList, &customStrSize);
 
    char* strBuffer = (char *)malloc(customStrSize); 
    root.printTo(strBuffer, customStrSize-1);
    Serial.printf("Reserved size: %d, actual size: %d\n", customStrSize, strlen(strBuffer));
    module->sendJson(strBuffer, 200);
    free(strBuffer); 

    uint32_t freeMem = system_get_free_heap_size();
    Serial.printf("%s After /api/list Free heap mem: %d\n", NTP.getTimeDateString().c_str(), freeMem);   
  });
  
  // TODO: remove duplicated code with XIOTModule !!
  server->on("/api/rename", HTTP_POST, [&]() {
    char *forwardTo;
    XUtils::stringToCharP(server->header("Xiot-forward-to"), &forwardTo);
    String jsonBody = server->arg("plain");
    char message[100];
    
    // I've seen a few unexplained parsing error so I have set a bigger buffer size...
    const int bufferSize = 2* JSON_OBJECT_SIZE(2);
    StaticJsonBuffer<bufferSize> jsonBuffer; 
    JsonObject& root = jsonBuffer.parseObject(jsonBody); 
    if (!root.success()) {
      module->sendJson("{}", 500);
      if(strlen(forwardTo) != 0) { 
        oledDisplay->setLine(1, "Renaming agent failed", TRANSIENT, NOT_BLINKING);
      } else {
        oledDisplay->setLine(1, "Renaming master failed", TRANSIENT, NOT_BLINKING);
      }
      free(forwardTo);
      return;
    }
    // Forward the rename to an agent
    if(strlen(forwardTo) != 0) {     
      agentCollection->renameAgent(forwardTo, (const char*)root["name"]);
      free(forwardTo);
    } else {
      free(forwardTo);    
      if(config == NULL) {
        module->sendJson("{\"error\": \"No config to update.\"}", 404);
        return;
      }
      sprintf(message, "Renaming master to %s\n", (const char*)root["name"] ); 
      oledDisplay->setLine(1, message, TRANSIENT, NOT_BLINKING);
      config->setName((const char*)root["name"]);
      config->saveToEeprom(); // TODO: partial save !!   
      oledDisplay->setTitle(config->getName());
    }    
    module->sendJson("{}", 200);   // HTTP code 200 is enough
  });  
  /**
   * This API returns the SSID and PWD of the customized Access Point: modules will use it to connect to iotinator
   * NB: only 4 clients  can connect (TODO: to check!) 
   * => may be agent modules could also create an access point and act as relay for
   * other modules.
   **/
  server->on("/api/config", HTTP_GET, [](){
//    Serial.println("Rq on /api/config");
    char configMsg[JSON_STRING_CONFIG_SIZE];
    StaticJsonBuffer<JSON_BUFFER_CONFIG_SIZE> jsonBuffer;    
    // Create the root object
    JsonObject& root = jsonBuffer.createObject();
    root[XIOTModuleJsonTag::version] = API_VERSION ;
    root[XIOTModuleJsonTag::APInitialized] = config->isAPInitialized();
    root[XIOTModuleJsonTag::APSsid] = config->getApSsid(true);
    root[XIOTModuleJsonTag::APPwd] = config->getApPwd(true);
    root[XIOTModuleJsonTag::timestamp] = now();
    root[XIOTModuleJsonTag::homeWifiConnected] = homeWifiConnected;
    root[XIOTModuleJsonTag::gsmEnabled] = gsmEnabled;
    root[XIOTModuleJsonTag::timeInitialized] = ntpTimeInitialized;
    root.printTo(configMsg, JSON_STRING_CONFIG_SIZE);
    module->sendJson(configMsg, 200);
  });

  /**
   * This endpoint allows agent modules to register themselves to master when they initialize
   */
  server->on("/api/register", HTTP_POST, [](){
    char *jsonString;
    Serial.println("Registering module");
    // This will allocate jsonString
    XUtils::stringToCharP(server->arg("plain"), &jsonString);
    // agentCollection->add method need to copy the data since jsonString will be freed.
    Serial.println(jsonString); 
    Agent* agent = agentCollection->add(jsonString);
    free(jsonString);
    if(agent == NULL) {
      module->sendJson("{}", 500);
      oledDisplay->setLine(1, "Registration failed", TRANSIENT, NOT_BLINKING);
    } else {
      module->sendJson("{}", 200);
      if(agent->getToRename()) {
        agentToRename = agent;
      }
    }
    char message[100];
    sprintf(message, "Registered modules: %d", agentCollection->getCount());
    oledDisplay->setLine(2, message, NOT_TRANSIENT, NOT_BLINKING); 
    refreshOled2();   
  });

  /**
   * This endpoint allows removing a module
   */
  server->on("/api/register", HTTP_DELETE, [](){
    char *jsonString;
    Serial.println("Unregistering module");

  });

  // This endpoint is used by modules when they want to update data in the agent collection
  // (which is the data that the UI is polling)
  server->on("/api/refresh", HTTP_POST, [](){
    char *jsonString;
    Serial.println("Refreshing module");
    // This will allocate jsonString
    XUtils::stringToCharP(server->arg("plain"), &jsonString);
    // agentCollection->add method need to copy the data since jsonString will be freed.
    Serial.println(jsonString); 
    Agent* agent = agentCollection->refresh(jsonString);
    free(jsonString);
    if(agent == NULL) {
      module->sendJson("{}", 500);
      oledDisplay->setLine(1, "Refreshing failed", TRANSIENT, NOT_BLINKING);
    } else {
      module->sendJson("{}", 200);
    }          
  });
  
  // TODO: remove this or make it better. Needed during dev
  // reset may be only possible by SMS from admin number ?
  server->on("/api/swarmReset",  HTTP_GET, [](){
    Serial.println("Rq on /swarmReset");
    agentCollection->reset();
    config->initFromDefault();
    config->saveToEeprom();
    module->sendJson("{}", 200);
    gsm.sendSMS(config->getAdminNumber(), "Reset done");  // 
    WiFi.mode(WIFI_AP);
    initSoftAP();  
  });

  // OTA: update 
  server->on("/api/ota", HTTP_POST, [&]() {
    String forwardTo = server->header("Xiot-forward-to");
    String jsonBody = server->arg("plain");
    int httpCode = 200;
    if(forwardTo.length() != 0) {    
      Serial.print("Forwarding ota to ");
      Serial.println(forwardTo);
      module->sendJson("{}", httpCode);      
      char message[SSID_MAX_LENGTH + PWD_MAX_LENGTH + 40];
      sprintf(message, "{\"%s\":\"%s\",\"%s\":\"%s\"}", XIOTModuleJsonTag::ssid, config->getHomeSsid(), XIOTModuleJsonTag::pwd, config->getHomePwd());
      module->APIPost(forwardTo, "/api/ota", message, &httpCode, NULL, 0);
    } else {
      char message[200];
      sprintf(message, "{\"result\":\"OTA init on %s\"}", ipOnHomeSsid.c_str());
      module->sendJson(message, httpCode);      
      delay(200);
      WiFi.mode(WIFI_OFF);
      delay(400);
      WiFi.mode(WIFI_STA);   
      httpCode = module->startOTA(config->getHomeSsid(), config->getHomePwd());
    }
  });  
}
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
void loop() {

  if(module->isWaitingOTA()) {
    oledDisplay->refresh();
    ArduinoOTA.handle();
    return;
  }
    
  if(ntpEventToProcess) {
    ntpEventToProcess = false;
    processNtpEvent();
  }

  now();  // Needed to refresh the Time lib, so that NTP server is called
  // X seconds after reset, switch to custom AP if set
  if(defaultAP && (millis() > config->getDefaultAPExposition()) && config->isAPInitialized()) {
    defaultAP = false;
    initSoftAP();
  }
  
  // Check if main power is present
  int power = digitalRead(powerMonitorPin);
  if (power != HIGH) {
    oledDisplay->setLine(1, "POWER DOWN", NOT_TRANSIENT, NOT_BLINKING, NOT_COPY_SERIAL);
    if (XUtils::isElapsedDelay(millis(), &lastPowerAlertSent, POWER_ALERT_INTERVAL)) {
      gsm.sendSMS(config->getAdminNumber(), "POWER DOWN");  
    }
  
  } else {
    // lastPowerAlertSent = 0;  // TODO ? New alert if new power down.
  }
  
  // check if any new added agent needs to be renamed
  if(agentToRename != NULL) {
    agentCollection->autoRename(agentToRename);
    agentToRename = NULL;
  }
  
  // Check if any request to serve
  server->handleClient();
 
  // Let gsm do its tasks: checking connection, incomming messages, 
  // handler notifications...
  gsm.refresh();   
  
  // Display needs to be refreshed periodically to handle blinking
  oledDisplay->refresh();
  oledDisplay2->refresh();

  // Time on display should be refreshed every second
  // Intentionnally not using the value returned by now(), since it changes
  // when time is set.  
  timeNow = millis();
  
  if(timeNow - timeLastTimeDisplay >= 1000) {
    timeLastTimeDisplay = timeNow;
    timeDisplay();
  }
  if(timeNow - timeLastWifiDisplay >= 3500) {
    timeLastWifiDisplay = timeNow;
    // refresh wifi display every Xs to display both ssid/ips alternatively
    wifiDisplay();    
  }
      
  if(timeNow - timeLastPing >= MIN_PING_PERIOD*1000) {
    timeLastPing = timeNow; 
    agentCollection->ping();
    uint32_t freeMem = system_get_free_heap_size();
    Serial.printf("%s After ping Free heap mem: %d\n", NTP.getTimeDateString().c_str(), freeMem);
    refreshOled2();
  } 
  
  // Things to do only once after connection to internet.
  if(homeWifiFirstConnected) {
  // Init ntp   
    initNtp();
    registerToWebsite();
    homeWifiFirstConnected = false;
  } 
  readSerial();
}

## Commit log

2017-11-01 Added specialized display class Gsm class now implements a map of response handlers Network connection now reflected as an icon (with or without roaming) Sending SMS when registering admin fails
    [gsm.cpp, gsm.h, iotinator.ino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]
2017-11-05 Began drawing the breaboard prototype. Needed adding custom components to Fritzing
    [iotinator.fzz]
2017-11-08 Added prototype picture
2018-05-15 Now exposes the default AP Wifi ssid for a configurable delay so that modules can connect, and get the customized ssid through the /api/aconfig endpoint. Then switches to the customized ssid. The api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
2018-05-17 Fixed time count freezing during default Ssid exposition at init
    [iotinator.ino]
2018-05-17 Refactored Display initialization, solving an imaginary problem.
    [iotinator.ino]
2018-05-17 Big refactoring to have generic base class for all modules to handle wifi connection (default, custom, switching), display, getting config from master. (slave modules for now, master and slave-master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
2018-05-19 Fixed ArduinoJson usage. Fixed some registration issues
    [Slave.cpp, Slave.h, SlaveCollection.cpp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]
2018-05-20 Implemented periodical ping of registers slaves, except the ones registered with the canSleep flag Enforcing limitation on registration custom data size. Custom data is replaced with a marker when to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
    [Slave.cpp, Slave.h, SlaveCollection.cpp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]
2018-05-20 Better timings for periodical ping, default AP exposition time, ... Improved display and serial log usage Fixed registration retries
    [SlaveCollection.cpp, iotinator.ino, masterConfig.h]
2018-05-20 Now registering slaves (and deduplcating their names) under their MAC address. Using IP was silly. Will help keeping track of slaves that use the ESP8266 deep sleep feature.
2018-05-20 Implemented swarmReset API on master to reset all modules, and moduleReset API to reset one module... This resets the EEPROM content with default values. Does not empty the slaveCollection, but anywa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
    [Slave.cpp, Slave.h, SlaveCollection.cpp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]
2018-05-21 If ping failed, don't try t get info from ping response...
    [Slave.cpp]
2018-05-21 Semi working with "switch" module having a status on/off. Init is good, refresh is not. Modules scripts and css not dynamically loaded yet.
2018-05-21 Fixed empty collection api list call crashing issue Fixed module renaming issue
    [Slave.cpp, SlaveCollection.cpp]
2018-05-21 Now showing a toggle button. But does not call API yet
2018-05-23 Update README.md
    Adding info on current status
2018-05-23 Added switch init to false
2018-05-26 Adding Switch oled picture
2018-05-26 After a module got data forwarded from master, it now refreshes the data registered in master slave collection by a POST on /api/refresh This fixes a bug showing up on UI when it displayed obsolete d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
    [SlaveCollection.cpp, iotinator.ino]
2018-05-27 Removed useless serial print since display lines are also printed to serial
2018-05-27 Fixing memory leak when already registered module registers again (after a restart)
    [SlaveCollection.cpp]
2018-05-27 Prototype for 3D printed Oled case panel
    [oledPanel.scad, oledPanel.stl]
2018-05-27 First proto
    [oledPanel.scad]
2018-05-27 First 3D printed proto
    Prototype for 3D printed Oled case panel
    Prototype for 3D printed Oled case panel
    [oledPanel.scad, oledPanel.stl]
2018-05-27 Added a type to the config default structure, which is the type of module. The version number is not enough, because two different modules can be using the version 1 of their config structure, but bo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
2018-05-27 Fixed merge issue Cut the spacer cylinders to make sure not to break the thin glass layer
    [oledPanel.scad, oledPanel.stl]
2018-05-27 better 3D print
2018-06-02 first prototype for master module, using oledPanel oledPanel can now be parameterized to be used in other designs
    [oledPanel.scad, prototype.scad]
2018-06-02 First prototype
    [prototype.stl]
2018-06-02 Some adjustement after first print. Added cover.
    [oledPanel.scad, prototype.scad]
2018-06-03 Added back cover
    [cover.stl, prototype.scad]
2018-06-03 Adding prototype pictures
2018-06-03 Design improvements
    [cover.stl, prototype.scad]
2018-06-06 Added battery holders
    [battery.stl, prototype.scad]
2018-06-17 Added battery to prototype
2018-06-23 Adding picture of switch prototype
2018-06-23 Added finished switch module
2018-06-24 Added ESP-12E to boards picture
2018-06-24 Adding esp32 boards picture
2018-06-24 better picture for finished switch
2018-07-01 Using model.set to get rid of focus class on button. stupid bootstrap.
2018-07-01 Can now chose ntp server NTP init no longer in Home wifi connection callback (was causing reset when ntp unreachable)
    [iotinator.ino, masterConfig.h, messages_en.h]
2018-07-01 Nicer button style
2018-07-07 Fixed NTP init. Was going too fast: handled needs to be set before "begin"
    [iotinator.ino]
2018-07-07 Fixed tz init Added restart API
    [iotinator.ino]
2018-07-08 Added model of screen to make simulations
    [oledPanel.scad]
2018-07-09 Once NTP time is obtained, we don't care that much about retry failures => increased retry delay App: fire refresh timer after refresh response, no more interval.
    [iotinator.ino]
2018-07-14 Replaced "slave" with "agent" to avoid problems when Skynet rules the world.
    [Agent.cpp, Agent.h, AgentCollection.cpp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]
2018-07-21 Few various ping-related minor fixes
    [Agent.h, AgentCollection.cpp]
2018-08-04 New 90° rotated module
    [oledPanel.scad]
2018-08-27 Fixed bug 'connected' was reset when ping period is more than default
    [Agent.cpp, AgentCollection.cpp, iotinator.ino]
2018-08-27 First step in /api/list return payload modification: AgentCollection no longer builds the return payload
    [AgentCollection.cpp, iotinator.ino]
2019-08-22 PIN now in config
2019-09-07 When connection is lost, reset the GSM. Beware: if sim pin is not good, will exhaust the 3 tries in no time (will be fixed)
    [gsm.cpp, gsm.h]
2019-09-07 New hard reset, no longer blocking Hard reset when diconnected longer than a given delay Can now send command to SIM800 through ESP serial
    [gsm.cpp, gsm.h, iotinator.ino]
2019-09-15 new init queue for init messages fixed bugs reading incoming messages
    [gsm.cpp, gsm.h, iotinator.ino]
2019-09-15 Incoming messages now processed in next loop Now deleting only read messages to avoid loss and saturation
    [gsm.cpp, gsm.h, iotinator.ino]
2019-09-15 got interrupted while removing useless module index in 'list' response...
2019-09-21 Dispatching incoming SMS to module based on its name. Incoming SMS processing still buggy !
    [Agent.cpp, Agent.h, AgentCollection.cpp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]
2019-09-21 Fixed sms processing crash. for now.
    [gsm.cpp, iotinator.ino]
2019-09-28 Added main power off detection and SMS alert to Admin number
2019-09-28 Moved obsolete stuff to "prototype" folder Added new schematics, board view
    [battery.stl, cover.stl, iotinator.fzz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]
2019-10-25 Adding schematic
2020-05-30 faster GSM check & reset. Fixed a few warnings
    [main.cpp, masterConfig.h]
2021-06-19 replaced type byte with unsigned char, tried (and failed) improving GSM stability
    [AgentCollection.cpp, gsm.cpp, main.cpp]
